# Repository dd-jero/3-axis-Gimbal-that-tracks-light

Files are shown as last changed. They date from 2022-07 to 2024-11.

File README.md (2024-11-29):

# Embedded System Capstone Design Project

## ✔️프로젝트 명
Gimbal system that tracks light
## ✔️ 개발 기간
2022.05 ~ 2022.06
## ✔️ 팀원 
|윤대민|[김태완](https://github.com/Waan2y) |[이재영](https://github.com/dd-jero)|
| :---: | :---: | :---: |
|팀장, I2C 통신 및 데이터 처리|PWM 설정 및 서보 모터 제어|Tracking 로직 구현|

## ✔️ 개발 환경 
- Chipset: ATmega4809(MCU), MCP2221A(USB-to-UART/I2C Convertor)
- Sensor: MPU6050, GL5549
- Servo motor
- Programming: AVR registers manipulation with C/C++
- 3D printing: Autodesk 3ds Max, UltiMaker Cura, Ender-3

## ✔️ 개발 목표
- 타깃 조준을 유지하는 미사일 발사대 컨셉

## ✔️ 주요 기능

### I2C 통신
- 센서 데이터 수집: MPU6050 센서로부터 가속도 및 자이로 데이터 수집
- **Drift Calibration**
  1. 배열 초기화
  2. 자이로스코트 데이터 읽기
  3. 값 저장 및 차이 계산 
  4. 드리트프 오류 추정
  
### PWM 제어
- TCA 레지스터를 사용한 PWM 신호를 신호를 생성하고 서보 모터 제어

### ADC 데이터 처리 
- CDS 센서의 아날로그 입력을 읽고 평균값을 계산하여 센서 오프셋 보정
- **Offset 설정**
  1. 초기화 및 데이터 수집
  2. 오프셋 계산
- **Offset 보정**
  1. 오프셋 적용
  2. 평균 값 계산
  3. 이동 상태 결정

### Tracking 및 자세 제어
1. ADC 데이터 처리
    - 수직 및 수평 이동 상태 결정 위해 상하좌우 평균값을 비교
2. 움직임 상태 결정
    - 수직 및 수평 상태 플래그를 설정하여 움직임 방향 결정
    - 특정 임계값 기준 
3. 최종 위치 조정 
    - tracking 각도 기반의 수평 및 수직 상태에 따른 조정
    - 최종적으로 각도 변환 후 PWM 신호를 통해 서보 모터 제어 

## ✔️ 회로도
<p align="center"> circuit</p>

## ✔️ 시스템 구현 모델
<p align="center"> model</p>

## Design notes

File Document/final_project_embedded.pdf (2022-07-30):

### 임베디드시스템 설계/2021

# 사물 tracking 3축 짐벌

# 최종 보고서

2022. 6. 19

# 인하대학교 정보통신공학부 윤대민, 김태완, 이재영

### 임베디드 시스템 설계/2022

정보통신공학부
임베디드시스템 설계

# 연구목표

## - 제목: 사물 tracking 3축 짐벌

## - 주요내용

- 사용자의 움직임으로 인한 카메라의 움직임을 보상하여, 카메라가 3차원의 특정

지점에서 움직이지 않도록 보조하는 장치를 구현한다.

- 카메라가 물체를 tracking하는 경우, 위 기능을 위한 데이터에, tracking으로 인한

카메라의 움직임을 반영하여, tracking과 짐벌이 동시에 동작할 수 있는 알고리즘을

구현하고 검증한다.

# 짐벌 시스템 예시

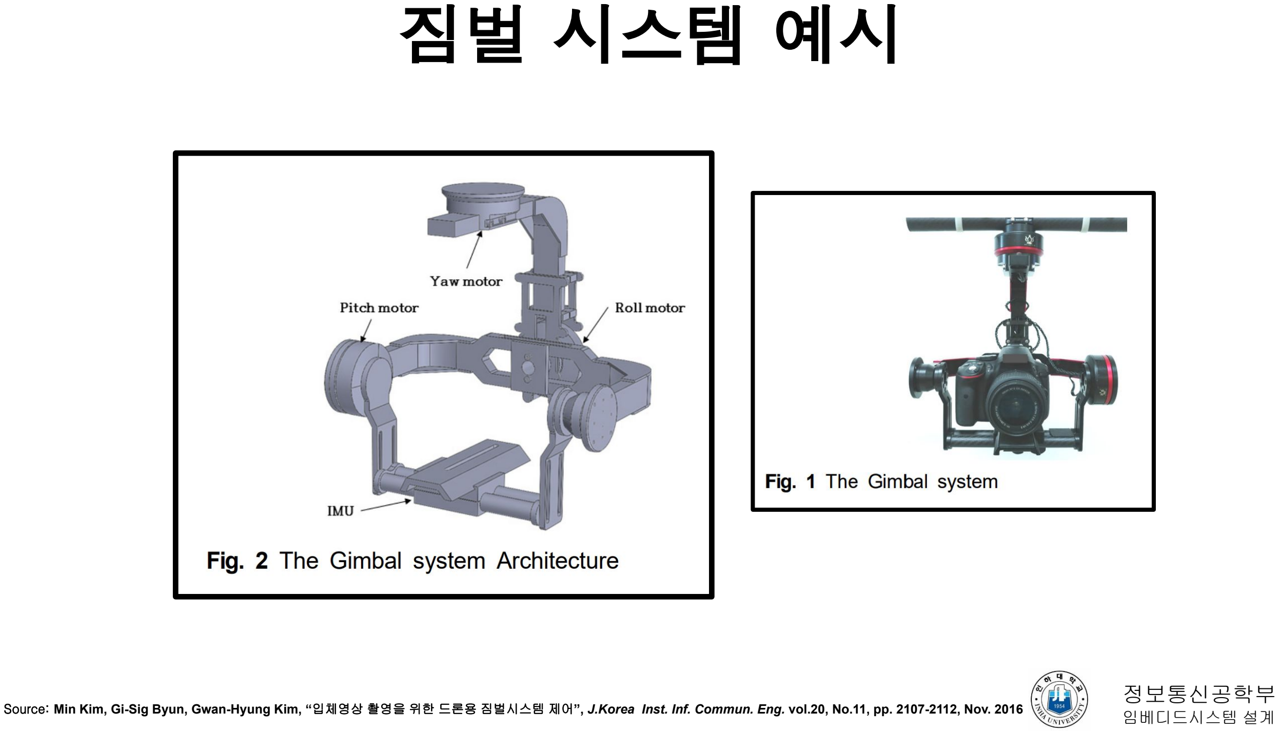
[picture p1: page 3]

Source: | Min Kim, Gi-Sig Byun, Gwan-Hyung Kim, “입체영상 촬영을 위한 드론용 짐벌시스템 제어”, J.Korea Inst. Inf. Commun. Eng. | vol.20, No.11, pp. 2107-2112, Nov. 2016

# 시스템 적용 예시

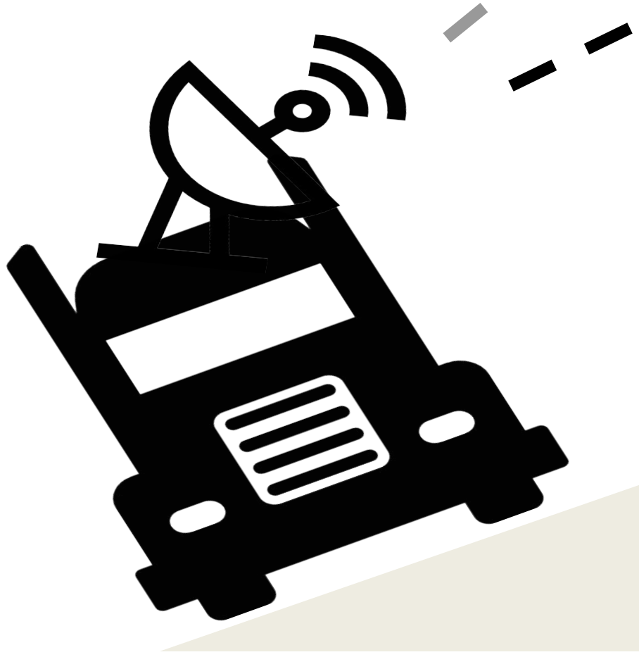
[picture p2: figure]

특정 타겟을 조준하고 있는 장비가 이동 중인 경우에도 조준을 유지할 수 있도록 한다.

# 시스템 구성 : Block Diagram

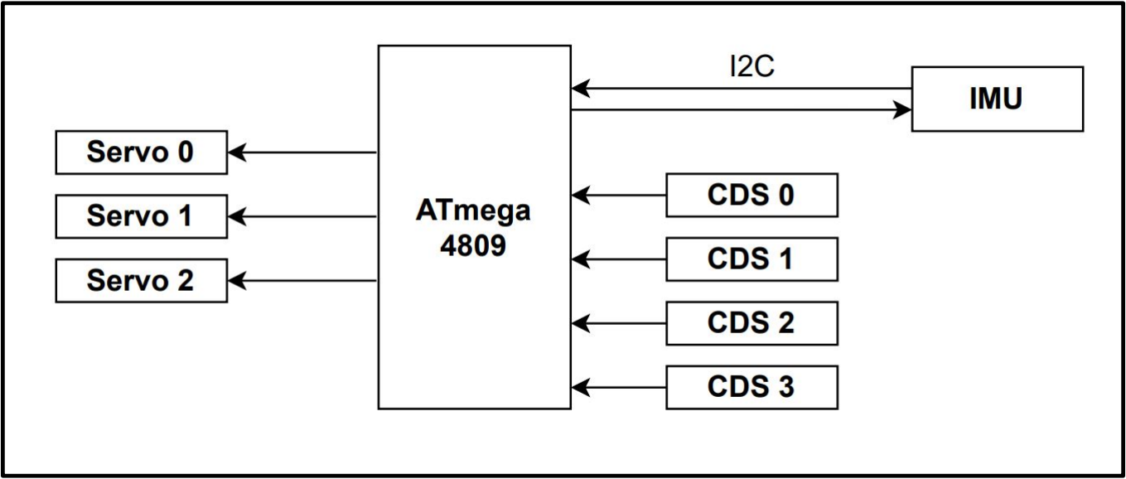
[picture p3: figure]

# 시스템 구성 : Flow-Chart

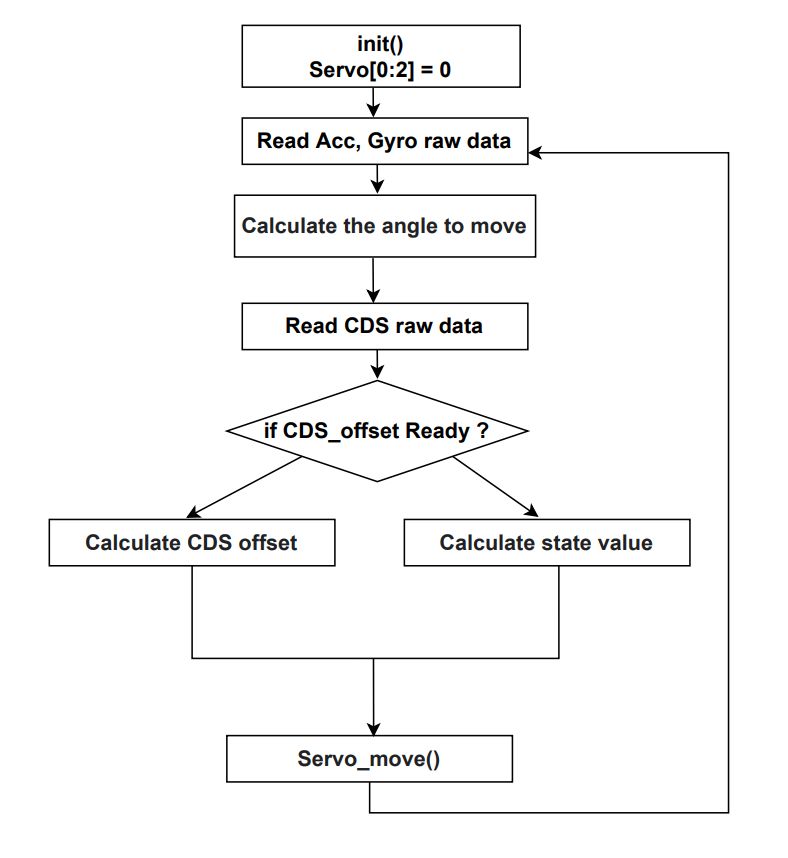
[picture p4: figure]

# 시스템 구성 : 회로도

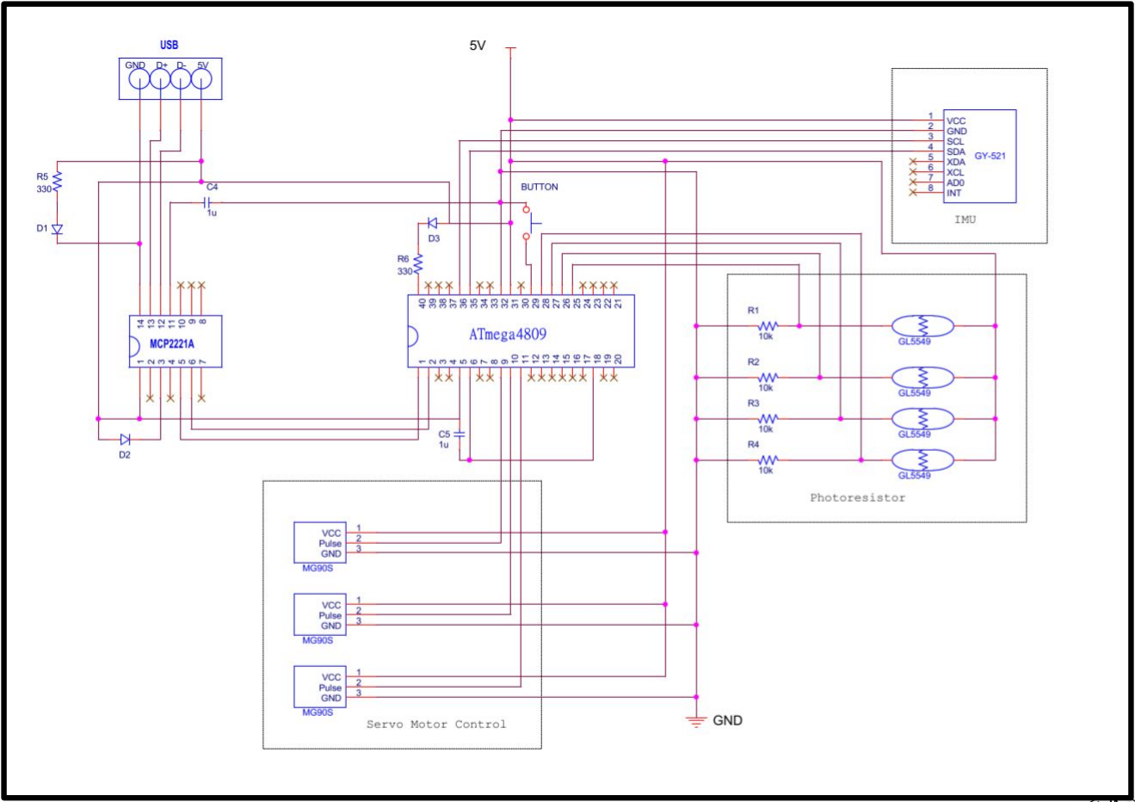
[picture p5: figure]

# 주요 부분 : 몸체

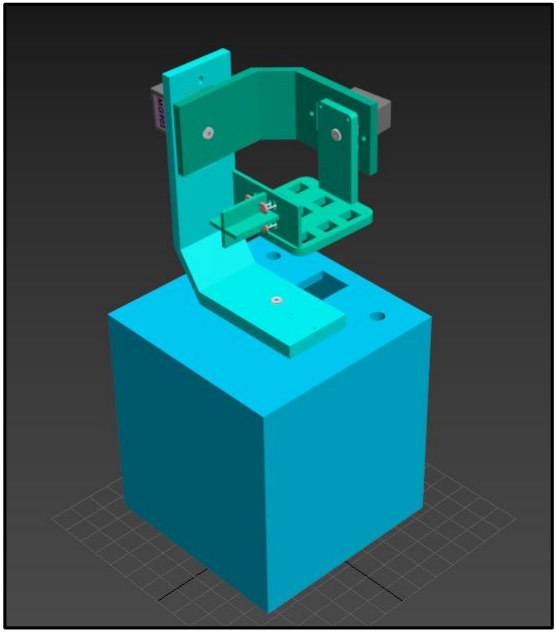
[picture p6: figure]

- 센서 측정값 수신
- IMU: 가속도, 각속도 측정값을 수신.

인터페이스: I2C

- 조도센서: 상하좌우 4방향에 해당하는 조도를 측정
- 데이터 취합 및 계산
- IMU의 측정값으로 Roll, Pitch, Yaw 정도를 계산
- CDS의 상/하, 좌/우 중 조도가 높은 방향(tracking 방향)

결정

- 기울기 보상을 위한 데이터와, tracking 을 위한 데이터를

계산하여 Servo의 이동 각도 산출

- 서보모터 제어
- 8-bit PWM

# 주요 기능 구현 : PWM

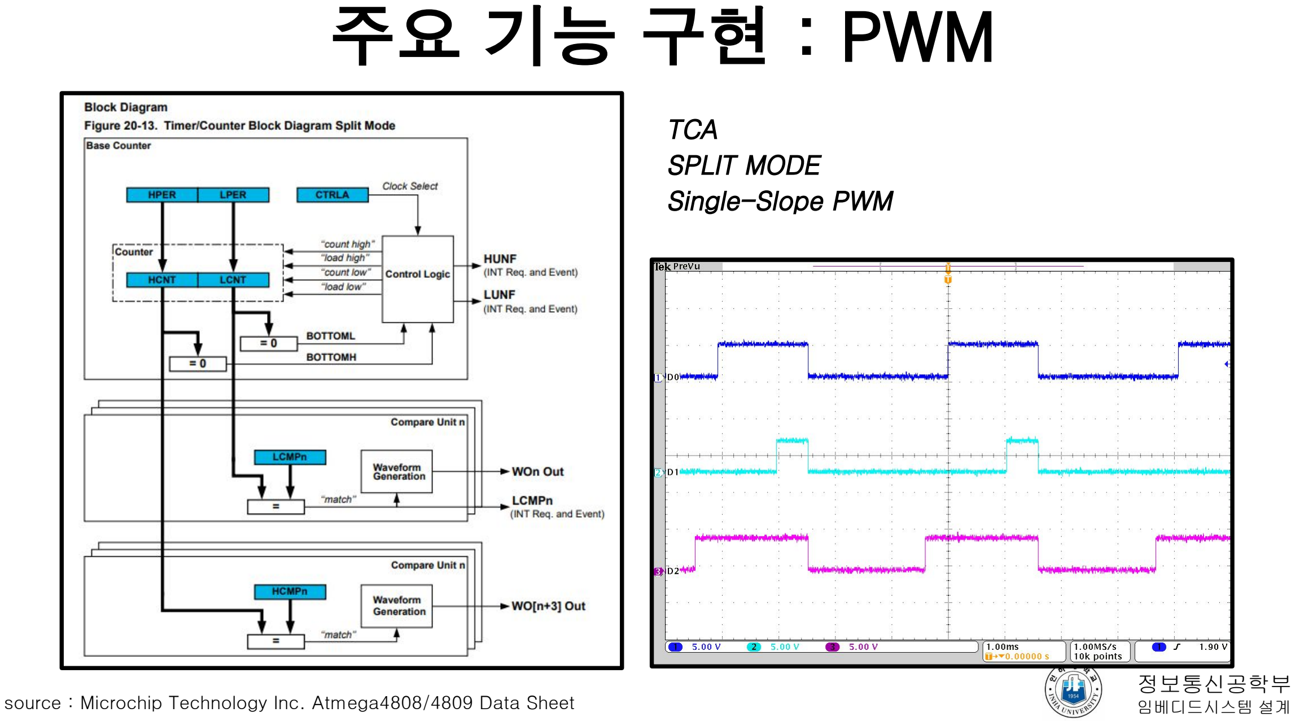
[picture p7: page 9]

TCA
SPLIT MODE
Single-Slope PWM

source : Microchip Technology Inc. Atmega4808/4809 Data Sheet

# 주요 기능 구현 : PWM

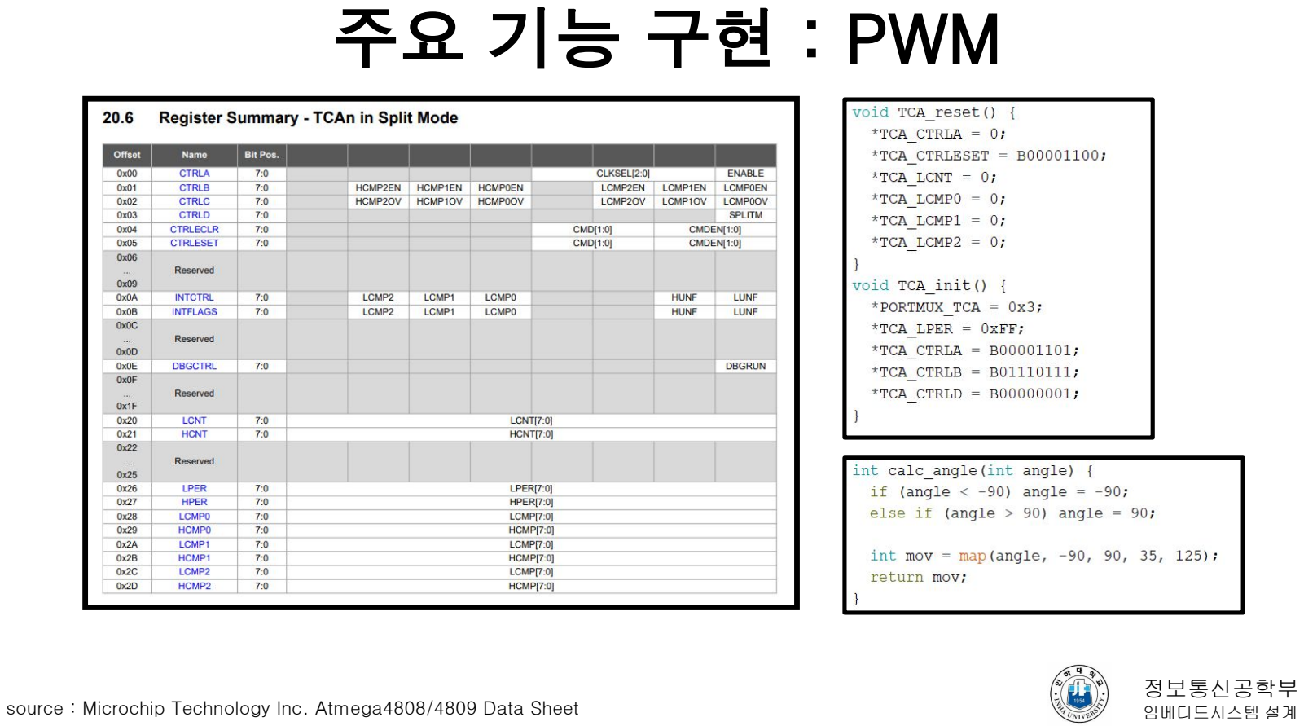
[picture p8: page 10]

source : Microchip Technology Inc. Atmega4808/4809 Data Sheet

# 주요 기능 : Tracking

- 조도 센서를 이용해서 광원의 위치를 파악한다.

### -상하좌우 4개의 조도센서를 사용하며, 각 조도센서로부터의 input이

동일해지도록 모듈을 제어한다.

- 광원 방향으로 이동하기 위해 서보모터에 전달해야 하는 값을 산출한다.

### - 자세 제어를 위해 계산한 데이터에 광원 트래킹을 위한 데이터를

더해줌으로써 두 종류의 기능이 동시에 동작하도록 한다.

# 주요 기능 구현 : ADC

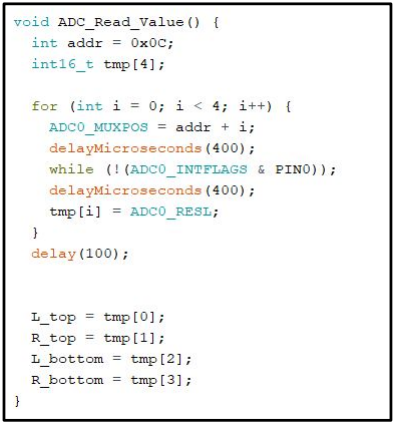
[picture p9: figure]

ADC의 MUXPOS Register를 이용하여 ADC 4개 채널 활용

- Atemga4809의 AIN12 ~ AIN15를 사용
=> 4개 CDS (GL5537)의 raw data 확인
- MUXPOS로 채널이 바뀌면서 settling time 필요 => 400us의 delay 부여
- 8bit resolution으로 0 ~ 255 값 출력
- ADC의 최대 분해능을 위해 CLK_PER를 16분주 (16MHz / 16 = 1MHz의 ADC Clock)

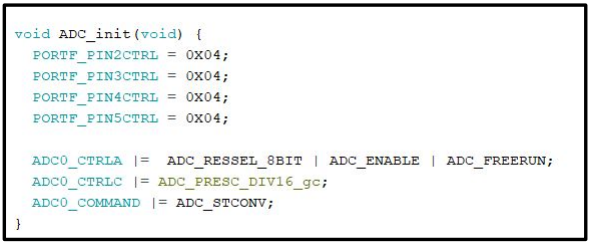
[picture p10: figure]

- Free Run Mode를 이용
=> conversion이 끝나자마자 새로운 conversion 시작

# 주요 기능 구현 : ADC

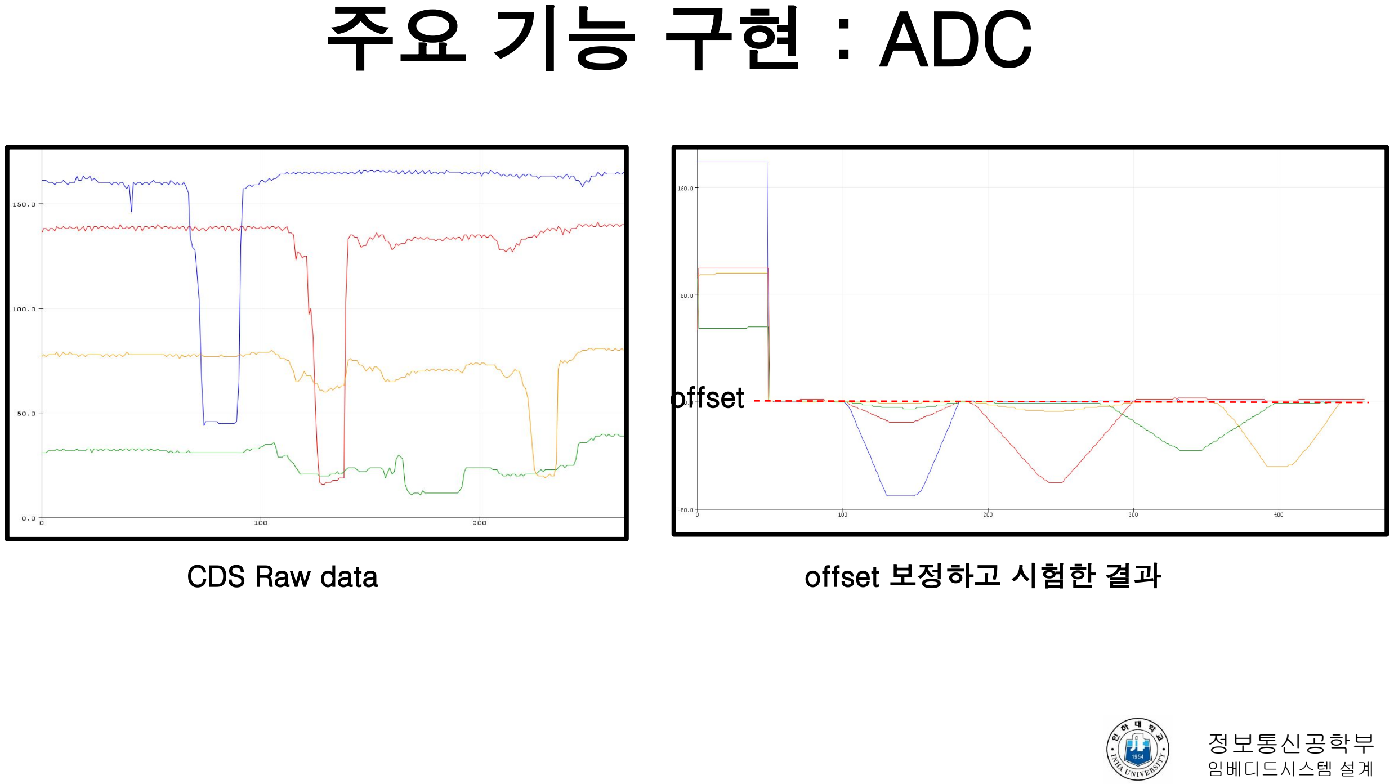
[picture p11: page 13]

CDS Raw data | offset 보정하고 시험한 결과

offset

# 주요 기능 구현 : ADC

### 환경적 요인을 고려한 raw data 보정

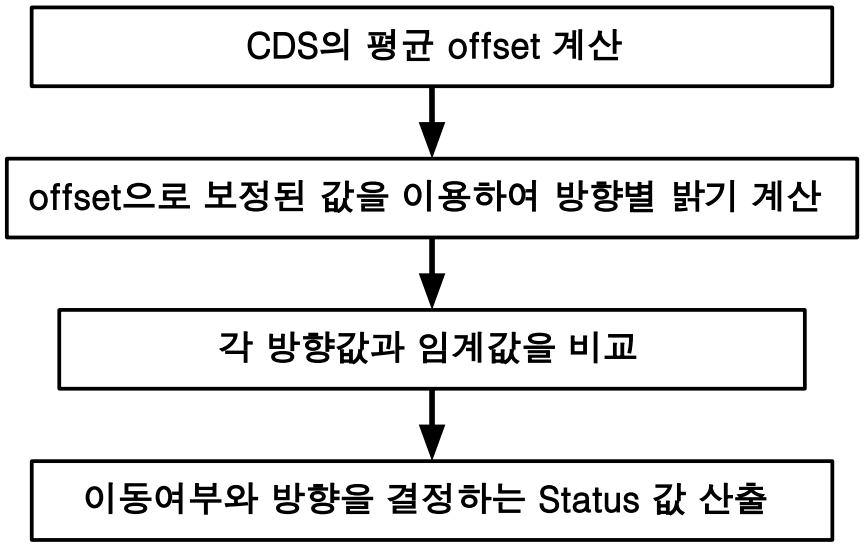
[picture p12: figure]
CDS의 평균 offset 계산; offset으로 보정된 값을 이용하여 방향별 밝기 계산; 각 방향값과 임계값을 비교; 이동여부와 방향을 결정하는 Status 값 산출

# 주요 기능 구현 : MPU6050

### 1. TWI_init

MCTRLA: twi_enable
MSTATUS: make bus idle

### 2. TWI_start

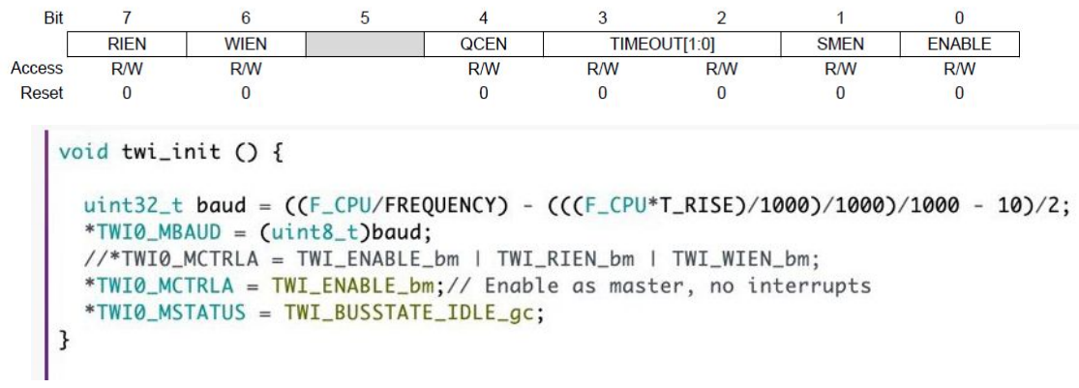
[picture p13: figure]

MADDR에 address <<1 | (RW’) 를 입력하면, MDATA를 거쳐 bus에 할당
polling 방식으로 WIF, RIF flag set을 기다림.
슬레이브로부터 ACK 수신을 감지하면 통신 종료

# 주요 기능 구현 : MPU6050

3. TWI_Write
start와 동일하게 전송하고자 하는 데이터를 mdata에 저장 MCTRLB에 통신 지속을 위해 TWI_MCMD_RECVTRANS 저장
4. TWI_Read
Read(0)은 데이터 read후 ACK를 전송. Read(1)은 데이터 read 후 NACK를 전송.
ACK 전송시 MCTRLB에 TWI_MCMD_RECVTRANS_gc 저장.
NACK 전송시 통신 종료를 위해 MCTRLB에 TWI_MCMD_STOP_gc 저장.

# 주요 기능 구현 : MPU6050

### 5. Sensor setting

*0x1A = 0x06 : 내장 LPF 사용

*0x1B = 0x08 : Scale range of gyro (±500°/s)

*0x1C = 0x00 : Scale range of accelerometer (±2g)

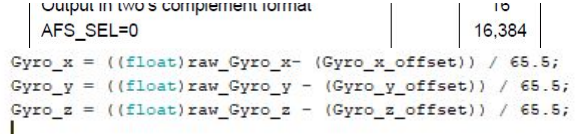
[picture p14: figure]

source : InvenSense Inc. MPU-6000/MPU-6050 Product Specification

# 주요 기능 구현 : MPU6050

### 6. 가속도 및 각속도 센서 값 수신

Burst read Sequence

해당 기능을 사용하여 0x3B로부터 Acx, Acy, Acz, temp, Gyx, Gyy, Gyz

총 14 바이트를 연속해서 Read할 수 있도록 작성

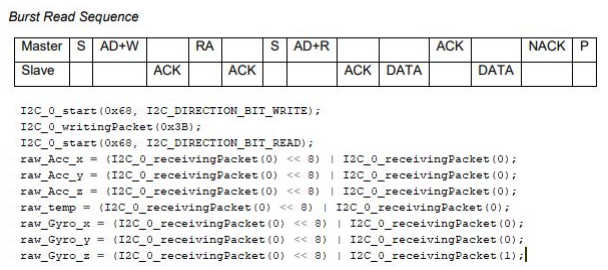
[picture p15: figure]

source : InvenSense Inc. MPU-6000/MPU-6050 Product Specification

# 주요 기능 구현 : MPU6050

### 7. Offset 계산

센서의 초기값에 오차가 있는 경우를 보정하기 위해 초기 100번의 평균값을 offset으로 설정

### 8. 각도 계산

가속도 센서: 중력 가속도 방향을 기준으로 Roll, Pitch 값을 얻을 수 있음

자이로 센서: 각 축을 기준으로 각속도를 적분하여 Roll, Pitch, Yaw값을 얻을 수 있음.

상보필터: 자이로센서와 가속도센서 계산 값을 상보필터에 적용하여, 정확성을 높일 수 있음.

장치의 움직임이 크지 않을 것이므로 각도 계산에는 가속도 센서값의 비중이 높은 상보필터를 사용

GyroCoef = 0.02

# 주요 기능 구현 : MPU6050

### 9. Drift Calibration

Yaw 값의 경우, 자이로센서 값만을 parameter로 사용. 따라서 누적되는 오차를 보정해 주는 알고리즘 추가

1. 정지 상태를 감지.

yaw 데이터 50개를 저장.

매 측정마다 데이터 변화량 49개를 저장. -> Diff 배열에 저장

Diff[0]과 Diff[48]의 평균과 전체 Diff의 평균의 특정 값 미만인 경우, 정지 상태로 판단.

2. Diff의 평균을 Drift로 간주
3. 계산한 drift값을 계산값에 적용하여 calibration 진행

# 주요 기능 구현 : MPU6050

### 9. Drift Calibration(상세 코드)

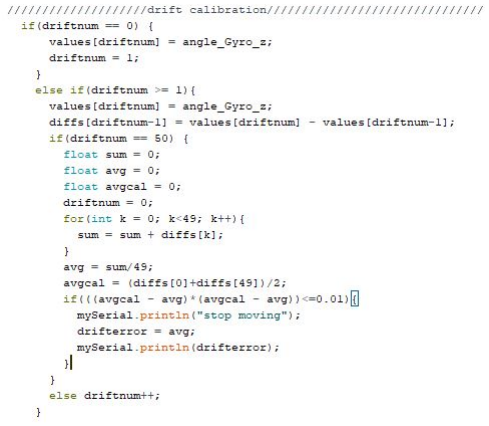
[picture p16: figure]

# 주요 기능 구현 : MPU6050

### Drift Calibration 검증

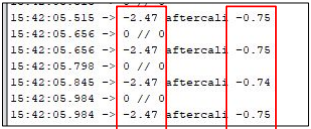
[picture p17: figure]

3분간 정지 상태 유지

calibration 이 적용되지 않은 경우 drift: -4°

calibration 알고리즘 적용한 경우 drift: -0.04°

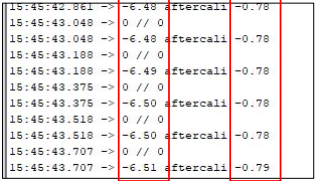
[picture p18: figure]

# 최종 기능 구현

### 1. 자세 제어 (짐벌) 앞서 계산된 각도 변화량만큼 반대로 서보모터를 구동함으로써 움직임을 보상해주도록 구현

# 최종 기능 구현

### 2. Tracking 4개의 input을 비교하여 Stay, move left, move right, move top, move bottom 5가지 state를 결정 하고, 계산된 각도에 Status를 반영하여 최종적으로 모터

제어.

# 최종 기능 구현

평균값의 차이가
threshold미만인 경우
target을 바라본다고 판단

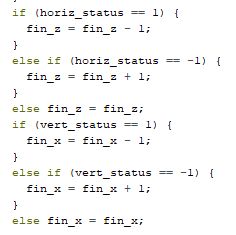
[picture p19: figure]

자세 변화 각도에, tracking을 위해 이동한 각도를 반영

=> 최종적으로 서보모터의 각도 결정
+
각도 유지를 위해 트래킹으로 인한 움직임을 저장

# 구현 중 문제점 및 고찰

### 1. 기기에 과도한 진동 발생

전기적 문제를 의심하였으나 전압, pwm signal이 모두 정상임을 확인. 특정 상태에서

무게중심이 문제가 되는 것을 확인하고 조정을 통해 보완

- 제품을 설계 할 때 전기적인 부분 외에도 다방면으로 고려해야 함을 인식

### 2. Tracking 알고리즘의 한계

자세 제어를 위해 움직였을 때, 축의 방향이 바뀌는 것을 고려하지 못함.

- 각도 범위를 지정하여 상태에 따라 축을 변경해주면 개선 가능할 것으로 예상

부품명 | 규격 (mm) | 모델/제조사 | 수량 | 가격(₩) | 비고
IMU | 21 x 11 x 1.5 | GY-521/ OEM | 1 | 3500/EA | I2C
조도센서 | 5.1 x 4.3 | GL5549/ OEM | 4 | 300/EA | -
서보모터 | 32.4 x 32.5 x 12 | MG90S/ OEM | 3 | 4200/EA | 무게 : 13.4g 토크 : 1.8kgf·cm
MCU | 50.8 x 15.24 x 5.06 | atmega4809/ MicroChip | 1 | - | -
배터리 | 60 x 34 x 50 | YJ Power Group YJ603450/ | 1 | 5500/EA | 3.7v 1000mAh 리튬폴리머배터리
만능기판 | 80 x 80 | - | 1 | 3000/EA | 양면

총 가격: 25800원

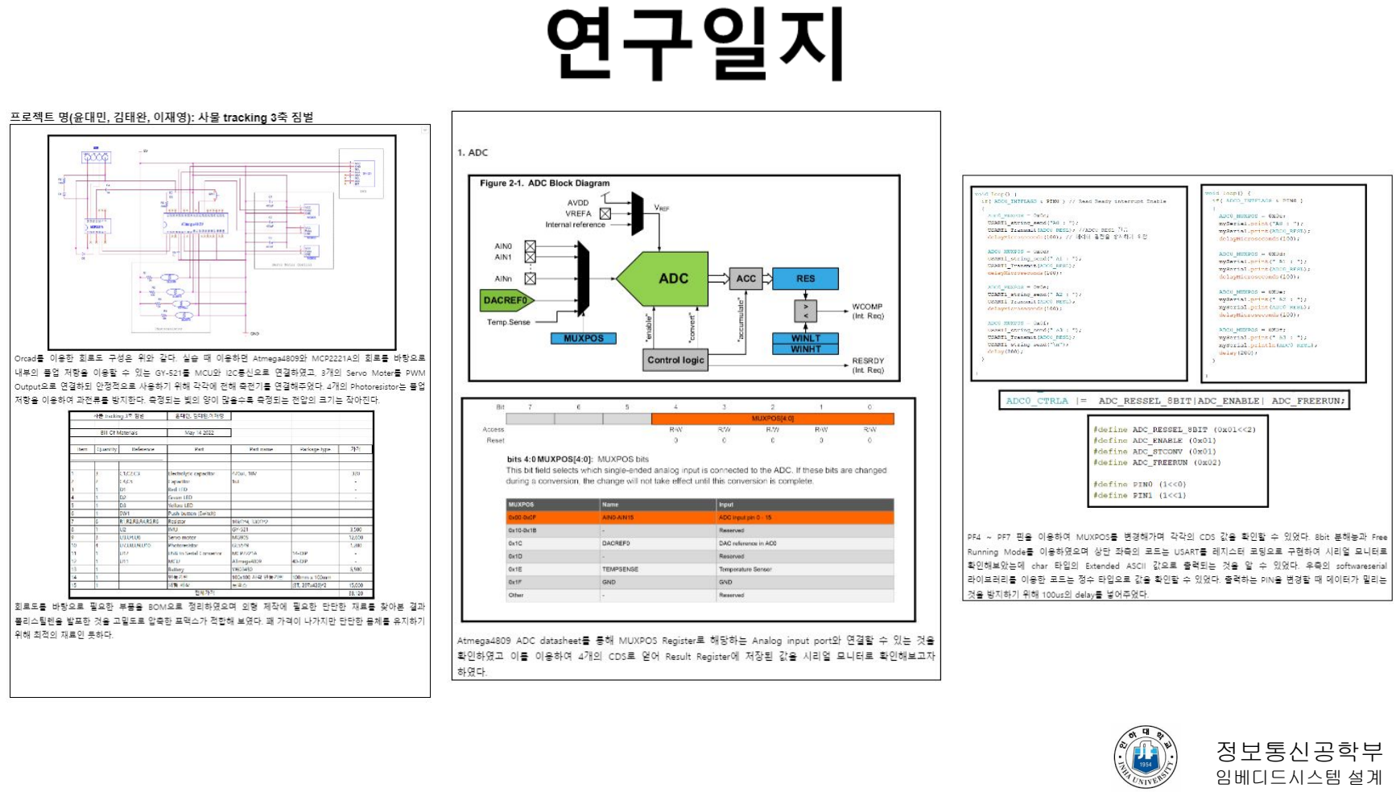
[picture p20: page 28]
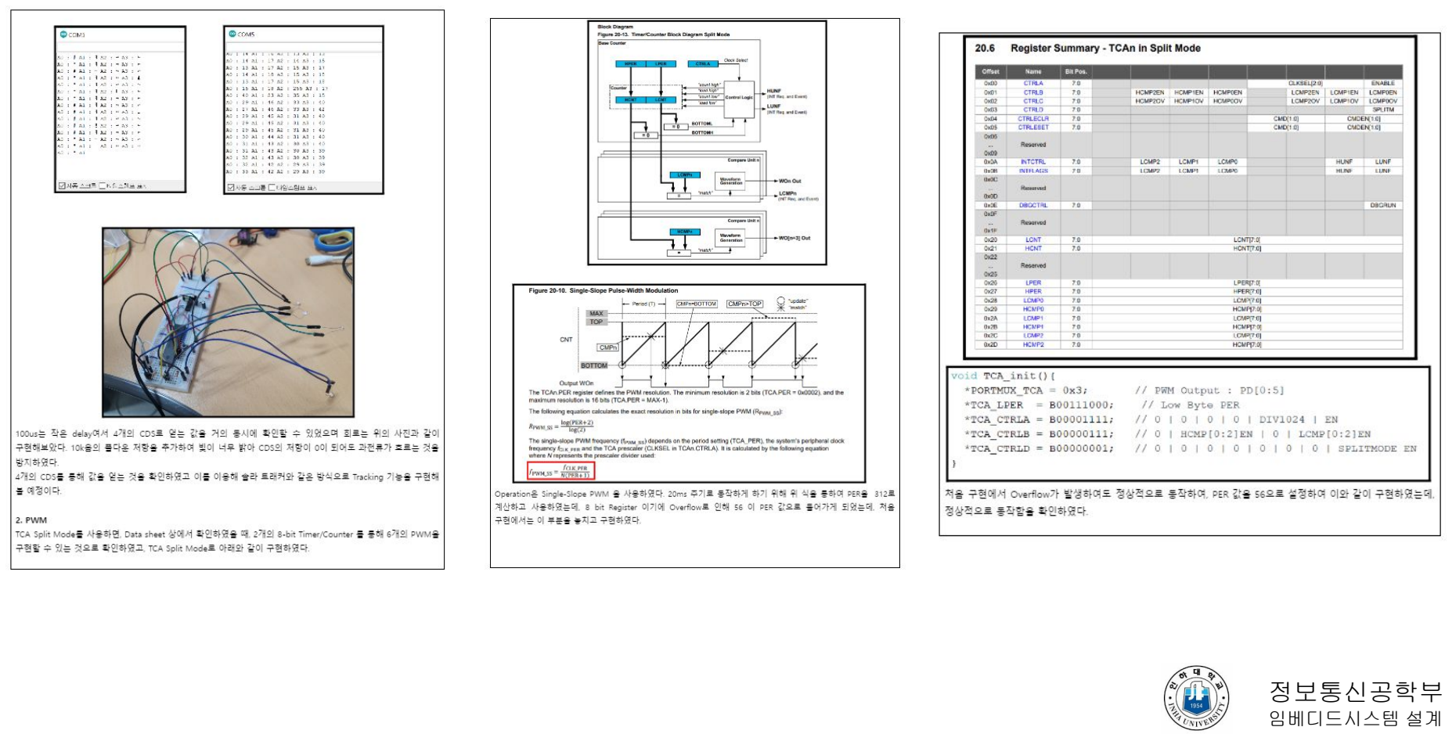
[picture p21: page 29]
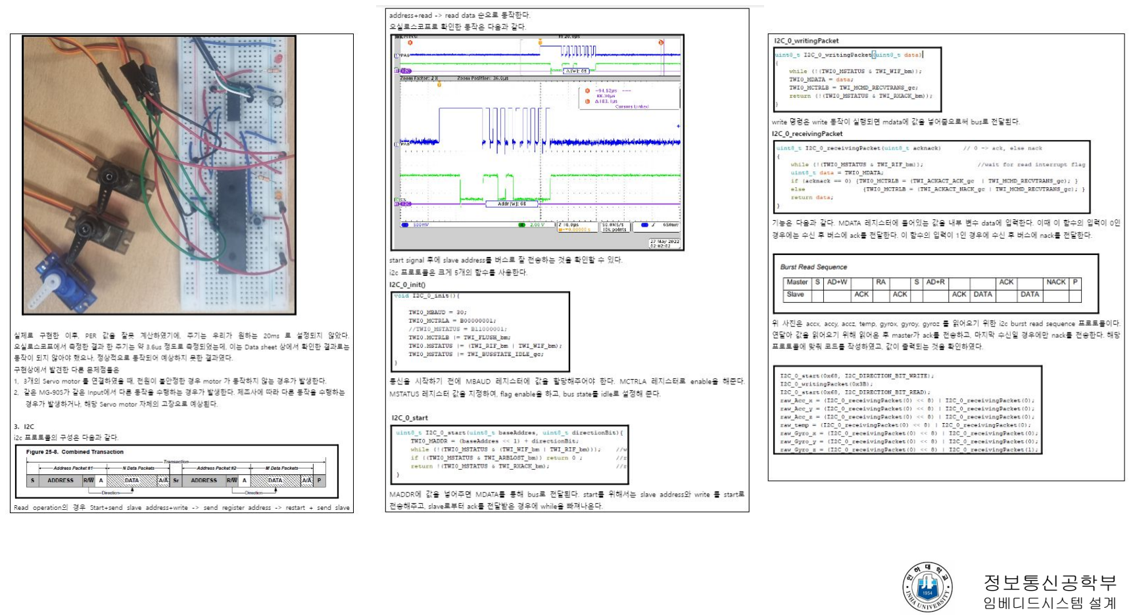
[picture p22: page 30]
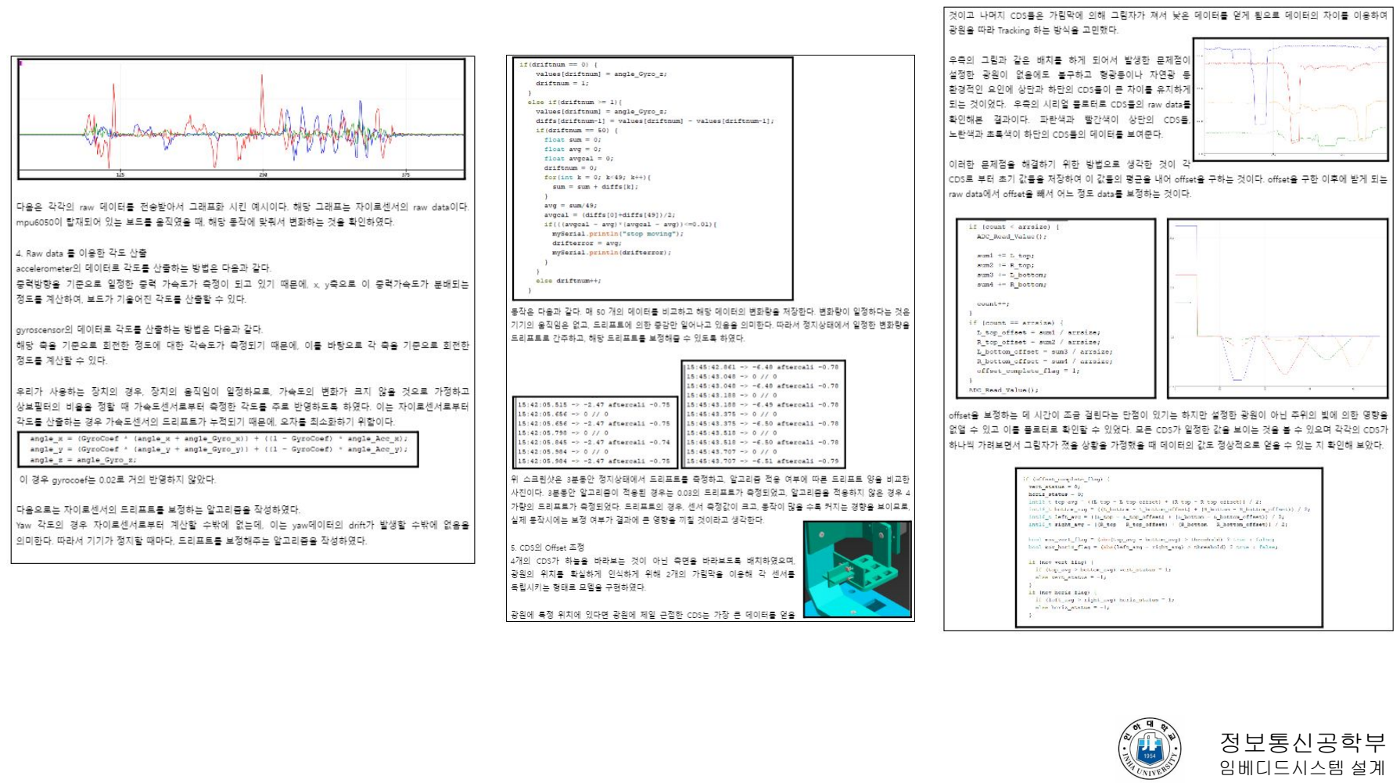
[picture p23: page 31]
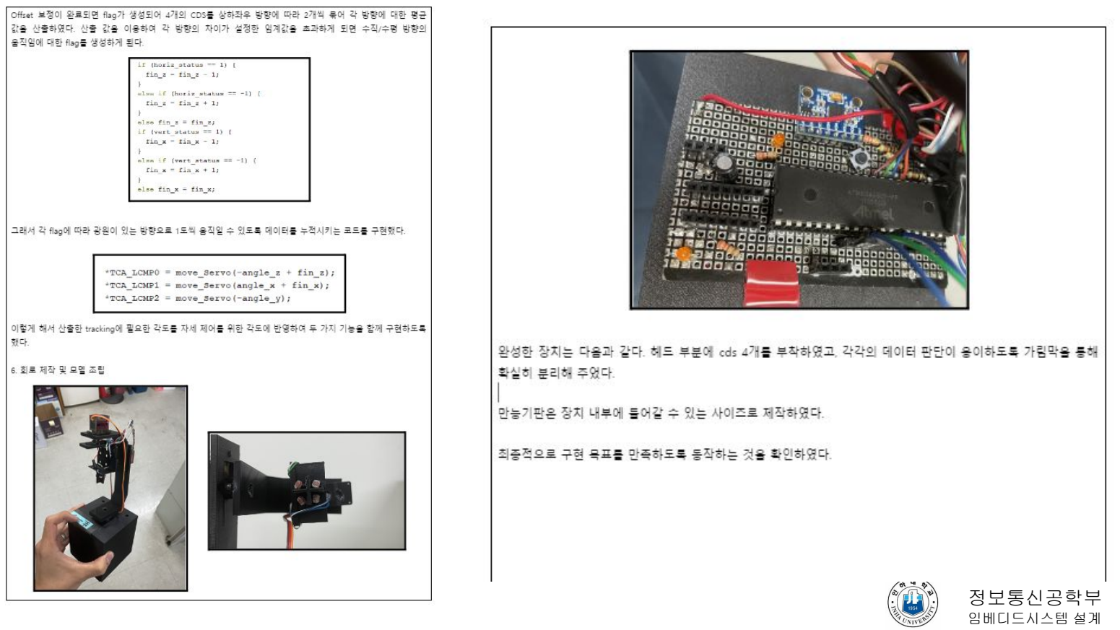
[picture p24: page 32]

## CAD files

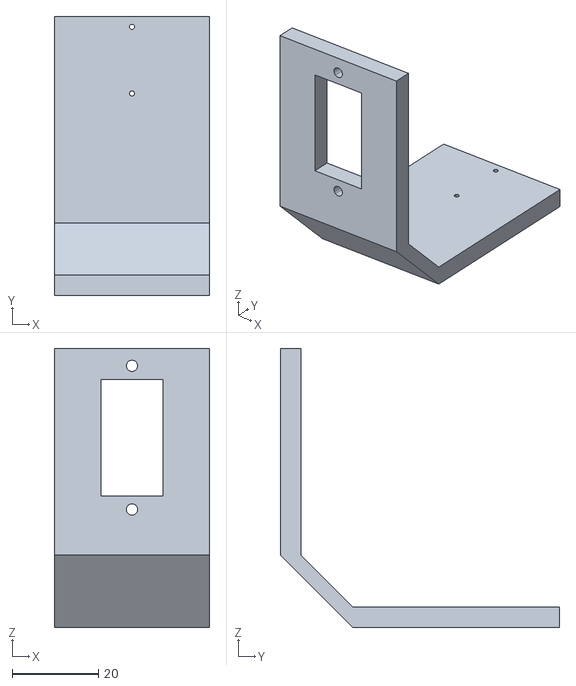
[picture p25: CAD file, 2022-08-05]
STL File/2sizeup.stl
36.0 x 64.8 x 64.8

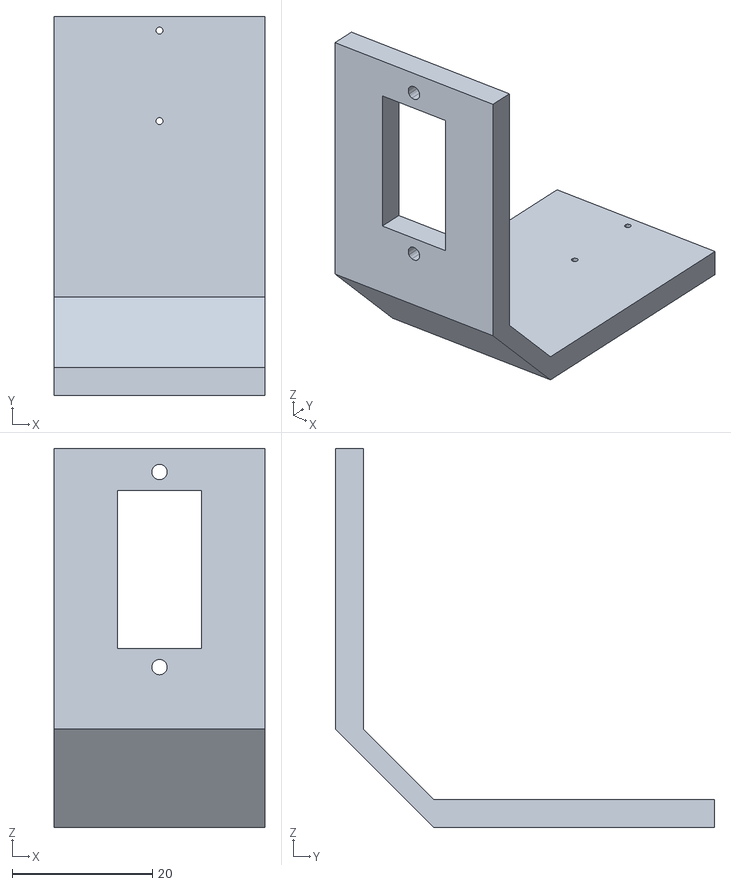
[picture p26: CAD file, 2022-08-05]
STL File/braket2.stl
30.0 x 54.0 x 54.0

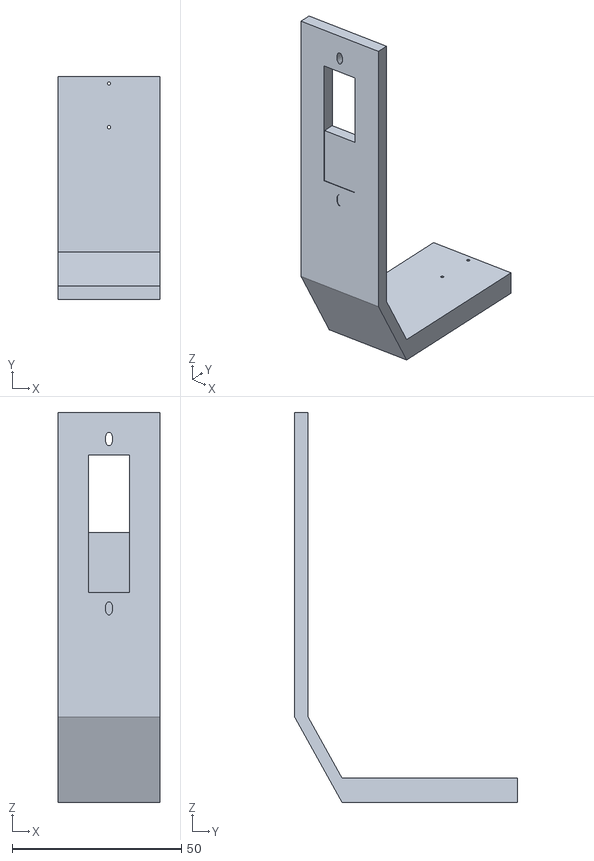
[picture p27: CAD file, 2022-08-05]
STL File/zaxis_115.stl
30.0 x 65.8 x 115.2

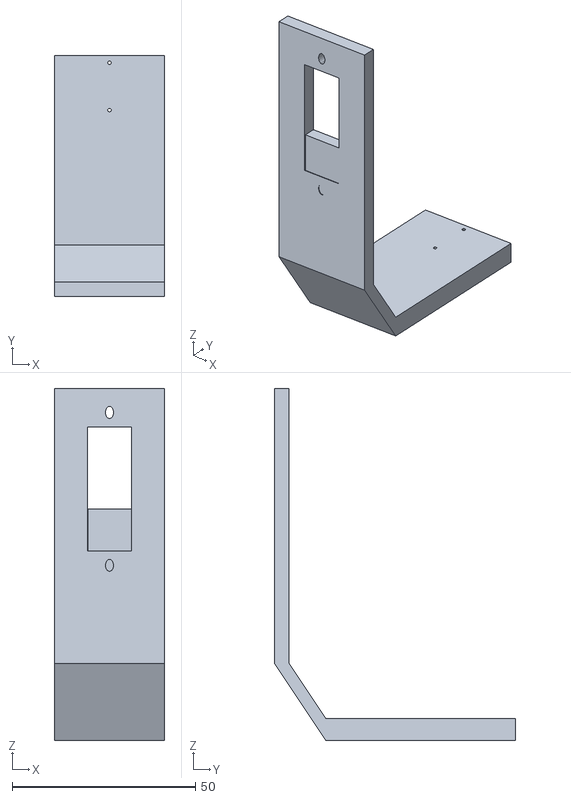
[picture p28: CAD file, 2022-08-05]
STL File/zaxis_10.stl
30.0 x 65.8 x 96.0

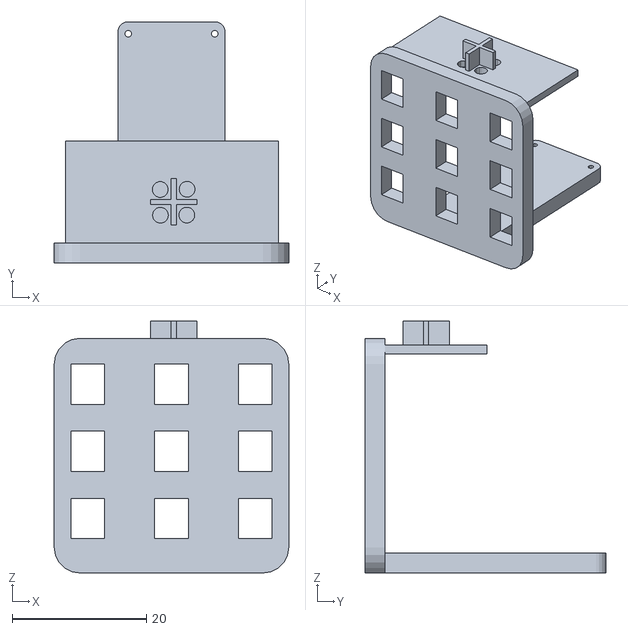
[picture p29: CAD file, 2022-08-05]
STL File/bracket_f.stl
35.0 x 36.0 x 37.6

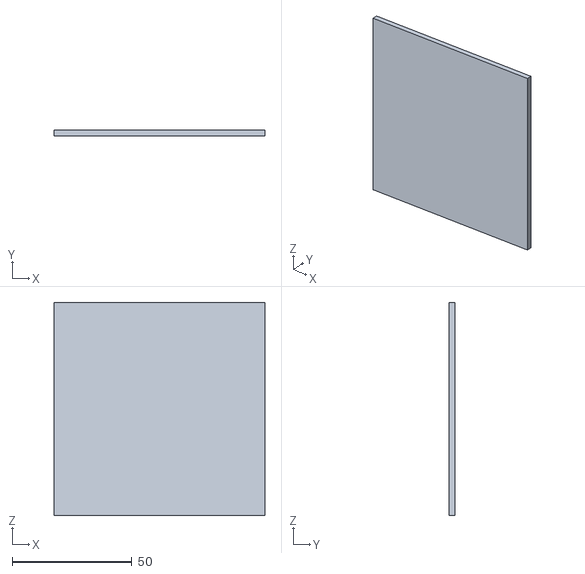
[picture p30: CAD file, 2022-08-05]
STL File/flat.stl
88.0 x 2.53 x 89.0

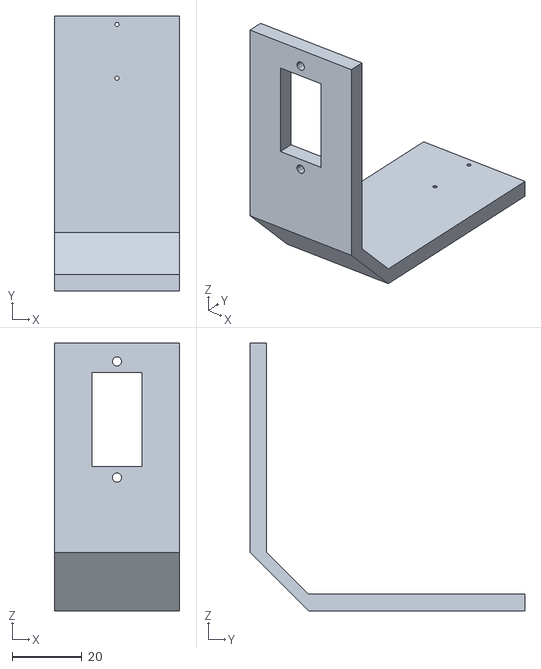
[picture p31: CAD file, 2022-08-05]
STL File/1sizeup.stl
36.0 x 78.9 x 76.8

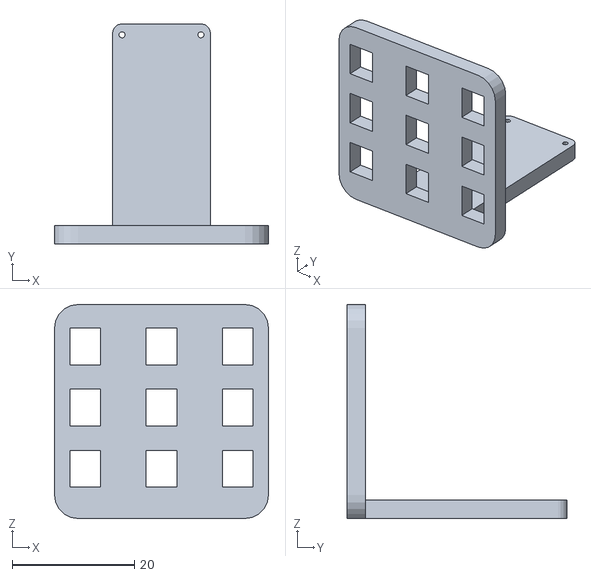
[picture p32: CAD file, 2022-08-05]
STL File/bracket.stl
35.0 x 36.0 x 35.0

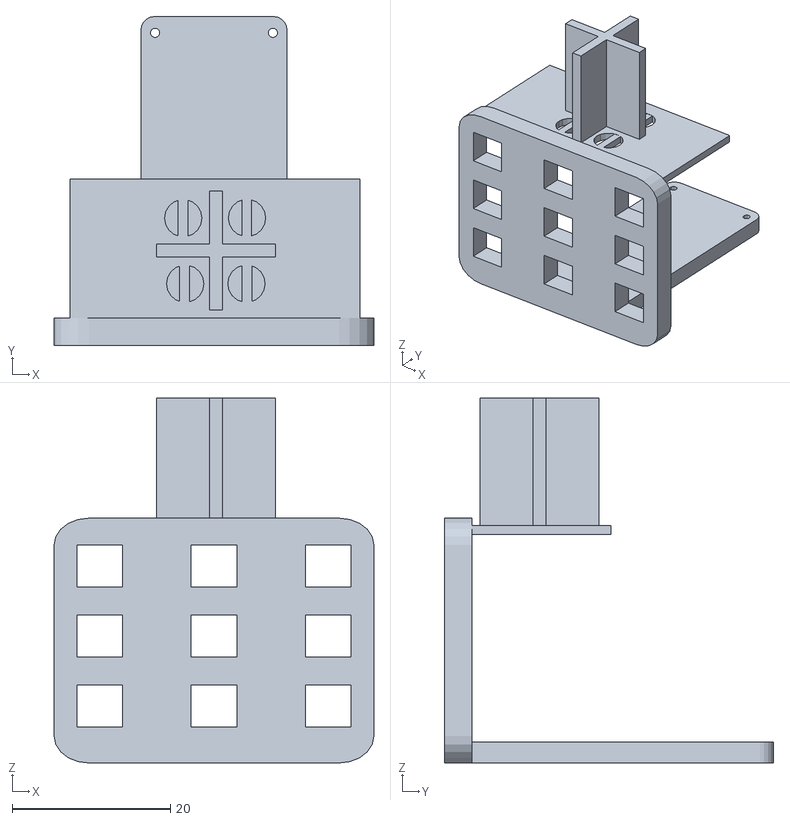
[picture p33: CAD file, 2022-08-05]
STL File/hole.stl
40.4 x 41.5 x 46.1

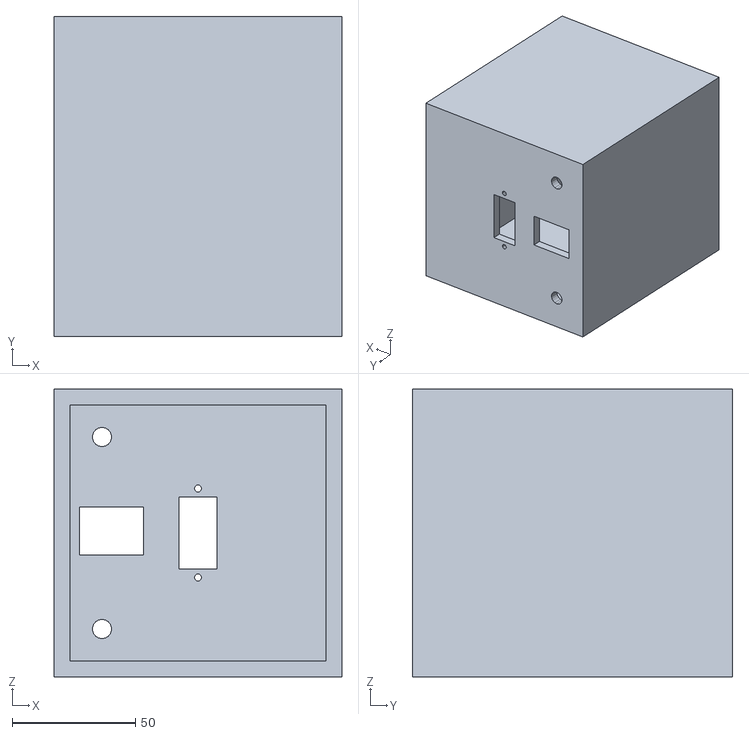
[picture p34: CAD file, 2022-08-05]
STL File/body_su.stl
117.0 x 130.0 x 117.0

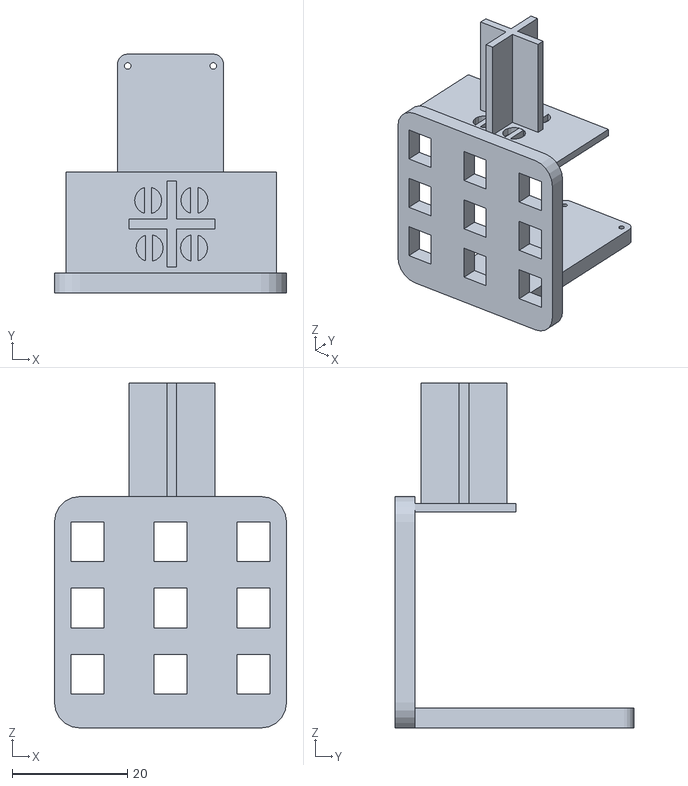
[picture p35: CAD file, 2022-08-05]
STL File/hole2.stl
40.4 x 41.5 x 60.0

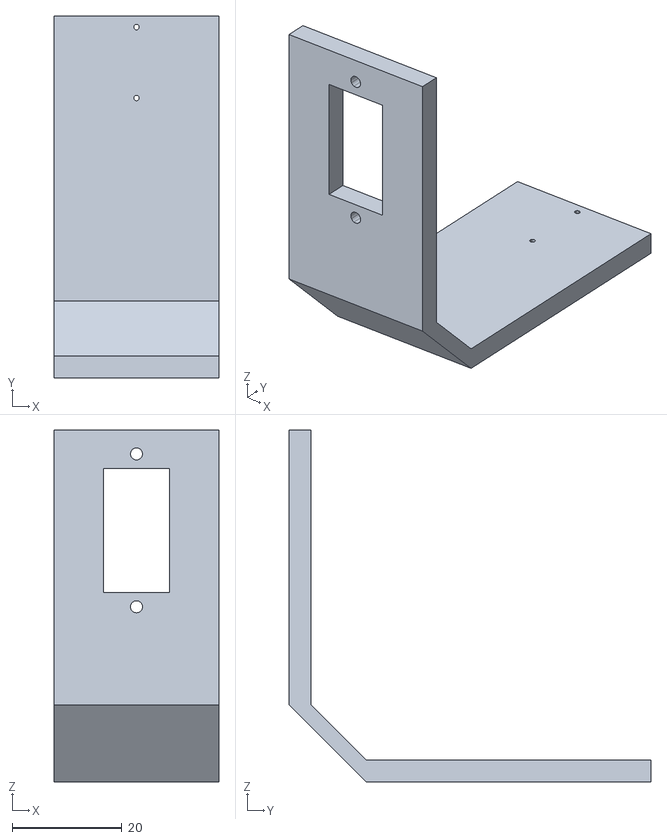
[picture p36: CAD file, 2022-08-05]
STL File/braket1.stl
30.0 x 65.8 x 64.0

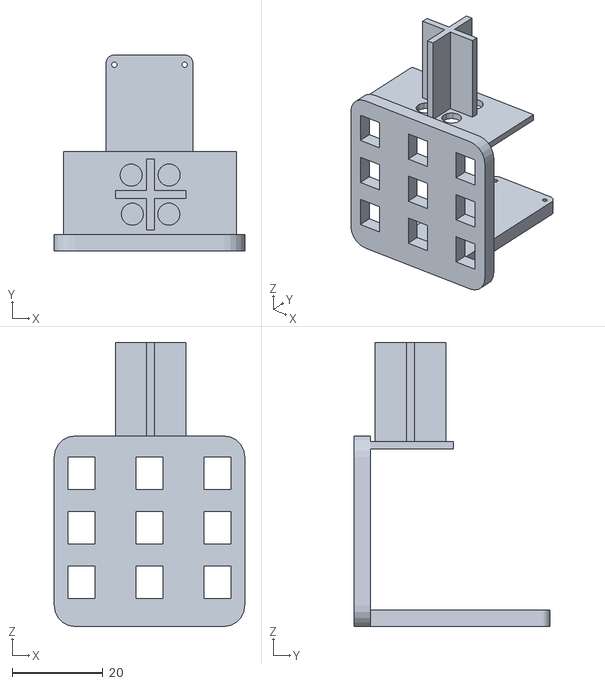
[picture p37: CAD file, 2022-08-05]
STL File/3sizeup.stl
42.0 x 43.2 x 62.6

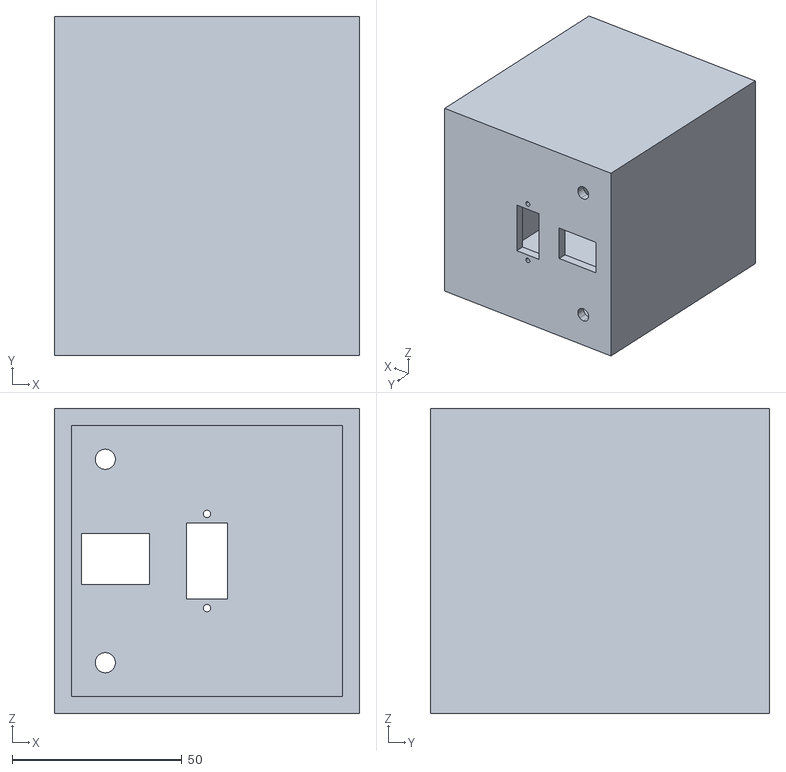
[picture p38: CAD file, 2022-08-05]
STL File/body.stl
90.0 x 100.0 x 90.0

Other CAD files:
STL File/zaxis.stl
STL File/flat_su.stl

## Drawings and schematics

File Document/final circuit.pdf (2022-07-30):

## IMU

5V

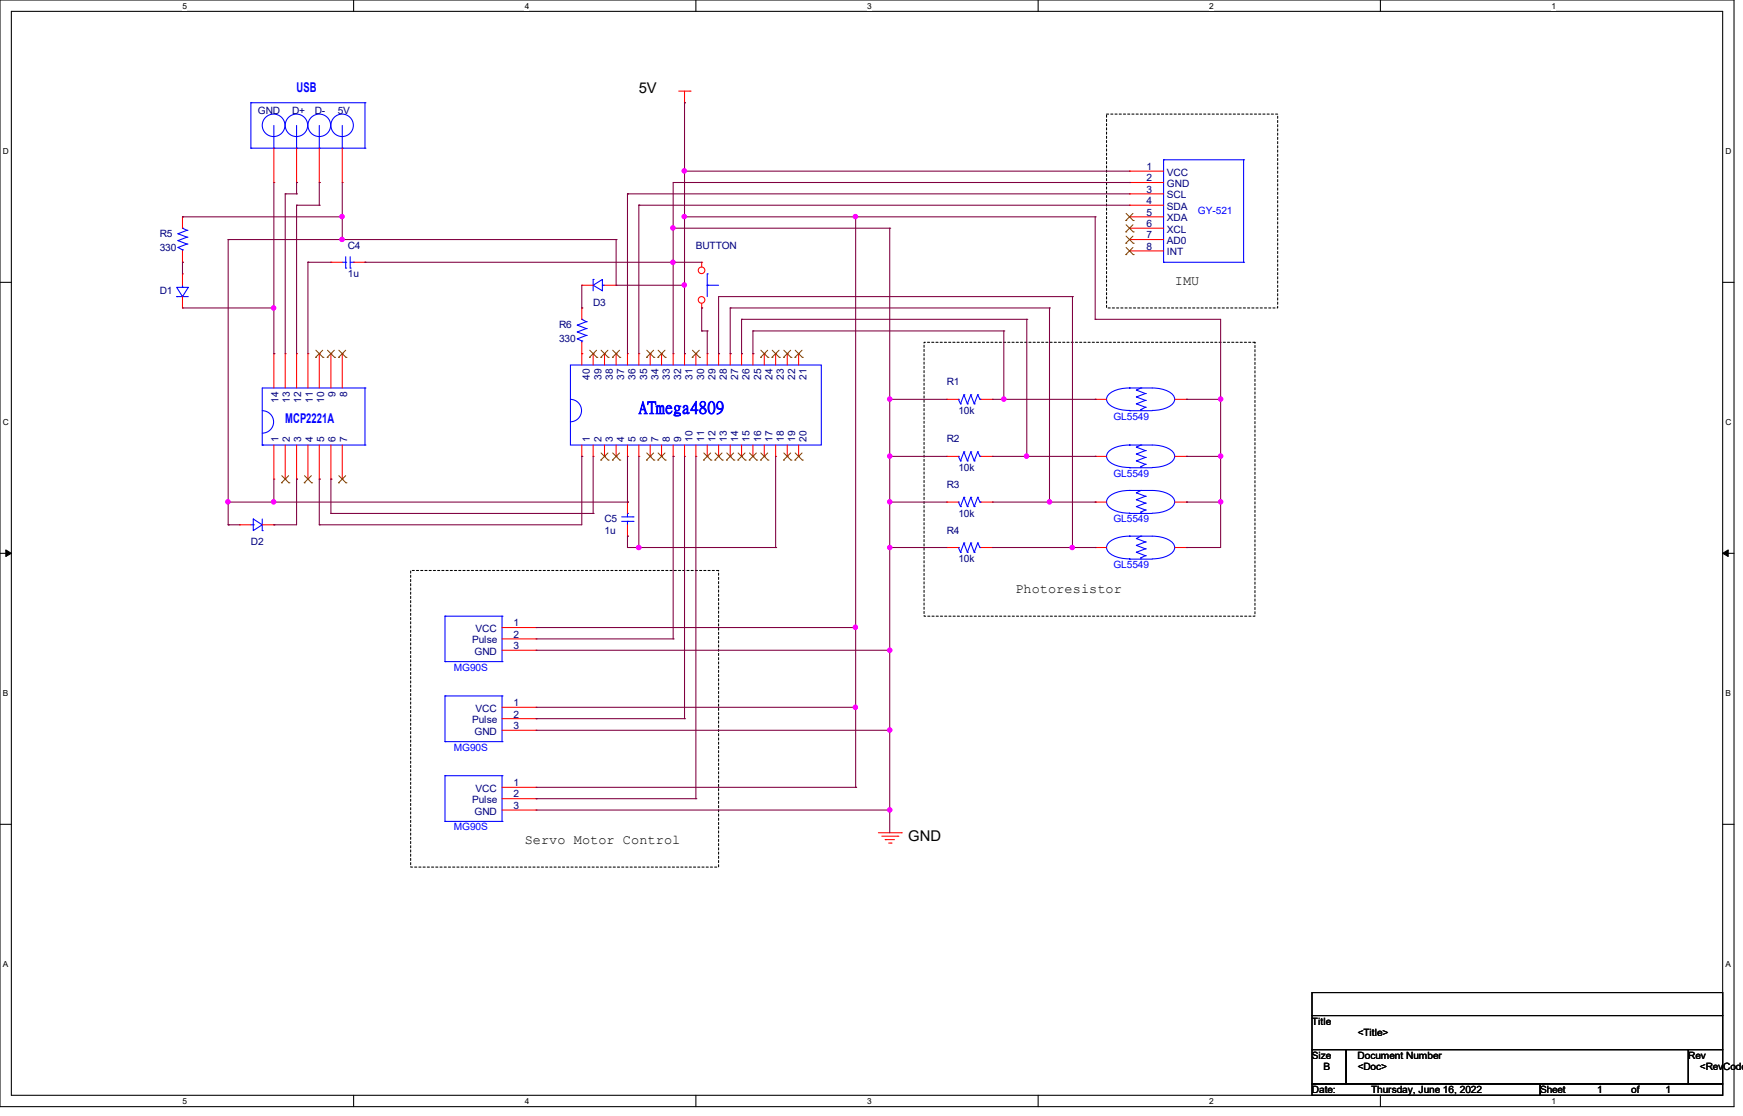
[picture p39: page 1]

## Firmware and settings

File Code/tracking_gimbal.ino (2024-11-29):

/*
    2022-1 임베디드시스템설계 최종프로젝트

    Team. 윤대민, 김태완, 이재영
    ver.  final_1
    date. 2022-06-15 14:49

    == Note ==
 *  * 정상 동작 시험 완료 *
    1. arrsize 커지면, 계산하는데 오래걸려서 빛을 지나쳐서 계속 가다 멈춰버림 -> arrsize 이제 사용 안해서 기능 없앰 함수 형태만 약간 수정
    2. x 축 다리길이 부족해서 걸림
    3. 이외 기능 모두 정상 동작
*/


// __ UART __ 구현상에서 사용하지는 않는 부분임. Data 확인 용
#include <SoftwareSerial.h>
SoftwareSerial mySerial(9, 8); // RX, TX

// __ I2C __

#define TWI0_BAUD(F_SCL)      ((((float)F_CPU / (float)F_SCL)) - 10 )
#define I2C_SCL_FREQ                                    400000
#define I2C_DIRECTION_BIT_WRITE                         0
#define I2C_DIRECTION_BIT_READ                          1
#define RAD_TO_DEG  (180 / 3.14159)

int16_t raw_Acc_x, raw_Acc_y, raw_Acc_z;
int16_t raw_temp;
int16_t raw_Gyro_x, raw_Gyro_y, raw_Gyro_z;
float Acc_x, Acc_y, Acc_z;
float Gyro_x, Gyro_y, Gyro_z;
float angle_Acc_x, angle_Acc_y, angle_Acc_z;
float angle_Gyro_x, angle_Gyro_y, angle_Gyro_z;
float angle_x = 0, angle_y = 0, angle_z = 0;
float Gyro_x_offset, Gyro_y_offset, Gyro_z_offset;
float Gyro_x_avg, Gyro_y_avg, Gyro_z_avg;
float fin_x, fin_y, fin_z;
float Interval;
float preInterval;
float cali_gyro;
float AccCoef = 0.98f;
float GyroCoef = 0.02f;


void I2C_0_init() {
  TWI0_MBAUD = 30;
  TWI0_MCTRLA = B00000001;
  //TWI0_MSTATUS = B11000001;
  TWI0.MCTRLB |= TWI_FLUSH_bm;
  TWI0.MSTATUS |= (TWI_RIF_bm | TWI_WIF_bm);
  TWI0_MSTATUS |= TWI_BUSSTATE_IDLE_gc;
}

void I2C_setup() {
  I2C_0_init();

  I2C_0_start(0x68, I2C_DIRECTION_BIT_WRITE);
  I2C_0_writingPacket(0x6B);
  I2C_0_writingPacket(0);
  I2C_0_stop();

  I2C_0_start(0x68, I2C_DIRECTION_BIT_WRITE);
  I2C_0_writingPacket(0x1A);
  I2C_0_writingPacket(0x06);
  I2C_0_stop();

  I2C_0_start(0x68, I2C_DIRECTION_BIT_WRITE);
  I2C_0_writingPacket(0x1B);
  I2C_0_writingPacket(0x08);
  I2C_0_stop();


  I2C_0_start(0x68, I2C_DIRECTION_BIT_WRITE);
  I2C_0_writingPacket(0x1C);
  I2C_0_writingPacket(0x00);
  I2C_0_stop();
}

uint8_t I2C_0_start(uint8_t baseAddres, uint8_t directionBit) {
  TWI0_MADDR = (baseAddres << 1) + directionBit;
  while (!(TWI0_MSTATUS & (TWI_WIF_bm | TWI_RIF_bm)));    //wait for write or read interrupt flag
  if ((TWI0_MSTATUS & TWI_ARBLOST_bm)) return 0 ;         //return 0 if bus error or arbitration lost
  return !(TWI0_MSTATUS & TWI_RXACK_bm);                  //return 1 if slave gave an ack
}

uint8_t I2C_0_writingPacket(uint8_t data) {
  while (!(TWI0_MSTATUS & TWI_WIF_bm));               //wait for write interrupt flag
  TWI0_MDATA = data;
  TWI0_MCTRLB = TWI_MCMD_RECVTRANS_gc;
  return (!(TWI0_MSTATUS & TWI_RXACK_bm));        //returns 1 if slave gave an ack
}

uint8_t I2C_0_receivingPacket(uint8_t acknack) {
  while (!(TWI0_MSTATUS & TWI_RIF_bm));               //wait for read interrupt flag
  uint8_t data = TWI0_MDATA;
  if (acknack == 0) {
    TWI0_MCTRLB = (TWI_ACKACT_ACK_gc  | TWI_MCMD_RECVTRANS_gc);
  }
  else                {
    TWI0_MCTRLB = (TWI_ACKACT_NACK_gc | TWI_MCMD_STOP_gc);
  }
  return data;
}

void I2C_0_stop(void) {
  TWI0_MCTRLB = (TWI_MCMD_STOP_gc);

}

void calcoffset() {
  int x = 0, y = 0, z = 0;
  uint16_t rx, ry, rz;
  for (int i = 0; i < 100; i++) {
    I2C_0_start(0x68, I2C_DIRECTION_BIT_WRITE);
    I2C_0_writingPacket(0x43);
    I2C_0_start(0x68, I2C_DIRECTION_BIT_READ);
    rx = (I2C_0_receivingPacket(0) << 8) | I2C_0_receivingPacket(0);
    ry = (I2C_0_receivingPacket(0) << 8) | I2C_0_receivingPacket(0);
    rz = (I2C_0_receivingPacket(0) << 8) | I2C_0_receivingPacket(1);

    x += ((float)rx);
    y += ((float)ry);
    z += ((float)rz);
  }

  Gyro_x_offset = x / 100;
  Gyro_y_offset = y / 100;
  Gyro_z_offset = z / 100;
}
// __ PWM __ ( via TCA )

#define PORTD_DIR   (unsigned char *)(0x0460)
#define PORTD_OUT   (unsigned char *)(0x0464)

#define PORTMUX_TCA (unsigned char *)(0x05E4)

#define TCA_CTRLA   (unsigned char *)(0x0A00)
#define TCA_CTRLB   (unsigned char *)(0x0A01)
#define TCA_CTRLD   (unsigned char *)(0x0A03)
#define TCA_CTRLESET     (unsigned char *)(0x0A05)
#define TCA_INTCTRL   (unsigned char *)(0x0A0A)
#define TCA_LCNT     (unsigned char *)(0x0A20)
#define TCA_HCNT     (unsigned char *)(0x0A21)
#define TCA_HPER     (unsigned char *)(0x0A26)
#define TCA_LPER     (unsigned char *)(0x0A27)
#define TCA_LCMP0    (unsigned char *)(0x0A28)
#define TCA_HCMP0    (unsigned char *)(0x0A29)
#define TCA_LCMP1    (unsigned char *)(0x0A2A)
#define TCA_HCMP1    (unsigned char *)(0x0A2B)
#define TCA_LCMP2    (unsigned char *)(0x0A2C)
#define TCA_HCMP2    (unsigned char *)(0x0A2D)

void TCA_reset() {
  *TCA_CTRLA = 0;
  *TCA_CTRLESET = B00001100;
  *TCA_HCNT = 0;
  *TCA_LCNT = 0;
  *TCA_HCMP0 = 0;
  *TCA_LCMP0 = 0;
  *TCA_HCMP1 = 0;
  *TCA_LCMP1 = 0;
  *TCA_HCMP2 = 0;
  *TCA_LCMP2 = 0;
}

void TCA_init() {
  *PORTMUX_TCA = 0x3;
  *TCA_LPER = 1250;
  *TCA_HPER = 1250;
  *TCA_CTRLA = B00001101;   // DIV1024
  *TCA_CTRLB = B01110111;
  *TCA_CTRLD = B00000001;   //SPLITMODE EN
  // *TCA_INTCTRL = B01110000;
  // TCA0.SINGLE.EVCTRL &= ~(TCA_SINGLE_CNTEI_bm);

}

void PORT_init() {
  *PORTD_DIR = B00011111;
  *PORTD_OUT = B00011111;
}

int move_Servo(int angle) {
  if (angle < -90) angle = -90;
  else if (angle > 90) angle = 90;

  int mov = map(angle, -90, 90, 32, 157);
  return mov;
}


// __ ADC __

#define ADC_RESSEL_10BIT (0x00<<2)
#define ADC_RESSEL_8BIT (0x01<<2)
#define ADC_ENABLE (0x01)
#define ADC_STCONV (0x01)
#define ADC_FREERUN (0x02)
#define PIN0 (1<<0)


int16_t tmp_L_top_offset = 0;
int16_t tmp_R_top_offset = 0;
int16_t tmp_L_bottom_offset = 0;
int16_t tmp_R_bottom_offset = 0;

int16_t L_top_offset = 0;
int16_t R_top_offset = 0;
int16_t L_bottom_offset = 0;
int16_t R_bottom_offset = 0;

int16_t L_top = 0;     // Left top
int16_t L_bottom = 0;  // Left bottom
int16_t R_top = 0;     // Right top
int16_t R_bottom = 0;  // Right bottom

int16_t avg_L_top = 0;     // prev Left top
int16_t avg_L_bottom = 0;  // prev Left bottom
int16_t avg_R_top = 0;     // prev Right top
int16_t avg_R_bottom = 0;  // prev Right bottom

int16_t avg_top;     // average top
int16_t avg_bottom;  // average bottom
int16_t avg_left;    // average left
int16_t avg_right;   // average right

int16_t threshold = 28;

void ADC_init(void) {
  PORTF_PIN2CTRL = 0X04; // PF0 interrupt and digital input buffer disabled
  PORTF_PIN3CTRL = 0X04; // PF1 interrupt and digital input buffer disabled
  PORTF_PIN4CTRL = 0X04; // PF2 interrupt and digital input buffer disabled
  PORTF_PIN5CTRL = 0X04; // PF3 interrupt and digital input buffer disabled

  ADC0_CTRLA |=  ADC_RESSEL_8BIT | ADC_ENABLE | ADC_FREERUN; // 8bit resolution and ADC enabled, FREERUN
  ADC0_CTRLC |= ADC_PRESC_DIV16_gc;
  ADC0_COMMAND |= ADC_STCONV; // Start conversion
}


void ADC_Read_Value() {
  int addr = 0x0C;
  int16_t tmp[4];

  for (int i = 0; i < 4; i++) {
    ADC0_MUXPOS = addr + i;             // A12~ (left top)
    delayMicroseconds(400);
    while (!(ADC0_INTFLAGS & PIN0));
    delayMicroseconds(400);
    tmp[i] = ADC0_RESL;
  }
  delay(100);                     // 가능하면 줄이고 싶음 ( ADC delay 싹다 )


  L_top = tmp[0];
  R_top = tmp[1];
  L_bottom = tmp[2];
  R_bottom = tmp[3];
}

void ADC_calc_AVG(int16_t L_top, int16_t R_top, int16_t L_bottom, int16_t R_bottom) {
  avg_top = (L_top + R_top) / 2;
  avg_bottom = (L_bottom + R_bottom) / 2;
  avg_left = (L_top + L_bottom) / 2;
  avg_right = (R_top + R_bottom) / 2;
}

// __ main_ setup __
void setup() {

  I2C_0_init();
  I2C_setup();
  calcoffset();

  mySerial.begin(115200);

  TCA_reset();
  TCA_init();
  PORT_init();
  *TCA_LCMP0 = move_Servo(0);
  *TCA_LCMP1 = move_Servo(0);
  *TCA_LCMP2 = move_Servo(0);

  ADC_init();
}

// __ main_ loop __
int count = 0;
int mov_vert = 0;
int mov_horiz = 0;
bool mov_vert_flag = false;
bool mov_horiz_flag = false;
int offset_flag = 1;
bool offset_complete_flag = false;

#define  arrsize 10
int16_t tmp1, tmp2, tmp3, tmp4;
int16_t sum1, sum2, sum3, sum4;
int horiz_status = 0;
int vert_status = 0;
//////////////////////////////////////////////////////////////////for drift calibration///////////////////////////////////////////////
int driftnum = 0;
float values[50] = {0};
float diffs[49] = {0};
float drifterror = 0;
float nocalibz = 0;

void loop() {
  //  _____ Read GY-521(MPU6050) via I2C _____

  I2C_0_start(0x68, I2C_DIRECTION_BIT_WRITE);
  I2C_0_writingPacket(0x3B);
  I2C_0_start(0x68, I2C_DIRECTION_BIT_READ);
  raw_Acc_x = (I2C_0_receivingPacket(0) << 8) | I2C_0_receivingPacket(0);
  raw_Acc_y = (I2C_0_receivingPacket(0) << 8) | I2C_0_receivingPacket(0);
  raw_Acc_z = (I2C_0_receivingPacket(0) << 8) | I2C_0_receivingPacket(0);
  raw_temp = (I2C_0_receivingPacket(0) << 8) | I2C_0_receivingPacket(0);
  raw_Gyro_x = (I2C_0_receivingPacket(0) << 8) | I2C_0_receivingPacket(0);
  raw_Gyro_y = (I2C_0_receivingPacket(0) << 8) | I2C_0_receivingPacket(0);
  raw_Gyro_z = (I2C_0_receivingPacket(0) << 8) | I2C_0_receivingPacket(1);

  // raw -> data
  Acc_x = ((float)raw_Acc_x) / 16384.0;
  Acc_y = ((float)raw_Acc_y) / 16384.0;
  Acc_z = ((float)raw_Acc_z) / 16384.0;

  angle_Acc_x = atan2(Acc_y, sqrt(Acc_z * Acc_z + Acc_x * Acc_x)) * 360 / 2.0 / PI;
  angle_Acc_y = atan2(Acc_x, sqrt(Acc_z * Acc_z + Acc_y * Acc_y)) * 360 / -2.0 / PI;

  Gyro_x = ((float)raw_Gyro_x - (Gyro_x_offset)) / 65.5;
  Gyro_y = ((float)raw_Gyro_y - (Gyro_y_offset)) / 65.5;
  Gyro_z = ((float)raw_Gyro_z - (Gyro_z_offset)) / 65.5;

  Interval = (millis() - preInterval) * 0.001;

  angle_Gyro_x += Gyro_x * Interval;
  angle_Gyro_y += Gyro_y * Interval;
  angle_Gyro_z += Gyro_z * Interval;
  //cali_gyro += Gyro_z * Interval;

  angle_x = (GyroCoef * (angle_x + angle_Gyro_x)) + ((1 - GyroCoef) * angle_Acc_x);
  angle_y = (GyroCoef * (angle_y + angle_Gyro_y)) + ((1 - GyroCoef) * angle_Acc_y);
  angle_z = angle_Gyro_z;
  angle_Gyro_z -= drifterror;
  mySerial.print(angle_z);
  mySerial.print(" aftercali ");
  mySerial.println(cali_gyro);
  preInterval = millis();
////////////////////drift calibration///////////////////////////////
  if(driftnum == 0) {
      values[driftnum] = angle_Gyro_z;
      driftnum = 1;
    }
    else if(driftnum >= 1){
      values[driftnum] = angle_Gyro_z;
      diffs[driftnum-1] = values[driftnum] - values[driftnum-1];
      if(driftnum == 50) {
        float sum = 0;
        float avg = 0;
        float avgcal = 0;
        driftnum = 0;
        for(int k = 0; k<49; k++){
          sum = sum + diffs[k];
        }
        avg = sum/49;
        avgcal = (diffs[0]+diffs[49])/2;
        if(((avgcal - avg)*(avgcal - avg))<=0.01){
          mySerial.println("stop moving");
          drifterror = avg;
          mySerial.println(drifterror);
        }
      }
      else driftnum++;
      delay(50);
    }


  //  _____ Read ADC _____
  if (count < arrsize) {
    ADC_Read_Value();

    sum1 += L_top;
    sum2 += R_top;
    sum3 += L_bottom;
    sum4 += R_bottom;

    count++;
  }
  if (count == arrsize) {
    L_top_offset = sum1 / arrsize;
    R_top_offset = sum2 / arrsize;
    L_bottom_offset = sum3 / arrsize;
    R_bottom_offset = sum4 / arrsize;
    offset_complete_flag = 1;
  }
  ADC_Read_Value();


  /*mySerial.print(L_top - L_top_offset);
    mySerial.print(" , ");
    mySerial.println(R_top - R_top_offset);
    //mySerial.print(",");
    mySerial.print(L_bottom - L_bottom_offset);
    mySerial.print(" , ");
    mySerial.println(R_bottom - R_bottom_offset);*/

  /*
    mySerial.print(avg_L_top - L_top_offset);
    mySerial.print(",");
    mySerial.print(avg_R_top - R_top_offset);
    mySerial.print(",");
    mySerial.print(avg_L_bottom - L_bottom_offset);
    mySerial.print(",");
    mySerial.println(avg_R_bottom - R_bottom_offset);*/

  if (offset_complete_flag) {
    vert_status = 0;
    horiz_status = 0;
    int16_t top_avg = ((L_top - L_top_offset) + (R_top - R_top_offset)) / 2;
    int16_t bottom_avg = ((L_bottom - L_bottom_offset) + (R_bottom - R_bottom_offset)) / 2;
    int16_t left_avg = ((L_top - L_top_offset) + (L_bottom - L_bottom_offset)) / 2;
    int16_t right_avg = ((R_top - R_top_offset) + (R_bottom - R_bottom_offset)) / 2;

    bool mov_vert_flag = (abs(top_avg - bottom_avg) > threshold) ? true : false;
    bool mov_horiz_flag = (abs(left_avg - right_avg) > threshold) ? true : false;

    if (mov_vert_flag) {
      if (top_avg > bottom_avg) vert_status = 1;
      else vert_status = -1;
    }
    if (mov_horiz_flag) {
      if (left_avg > right_avg) horiz_status = 1;
      else horiz_status = -1;
    }

    //mySerial.print(vert_status);
    //mySerial.print(" // ");
    //mySerial.println(horiz_status);
  }
  if (horiz_status == 1) {
    fin_z = fin_z - 1;
  }
  else if (horiz_status == -1) {
    fin_z = fin_z + 1;
  }
  else fin_z = fin_z;
  if (vert_status == 1) {
    fin_x = fin_x - 1;
  }
  else if (vert_status == -1) {
    fin_x = fin_x + 1;
  }
  else fin_x = fin_x;

//  mySerial.print(angle_z - fin_z);
//  mySerial.print(",");
//  mySerial.print(angle_x - fin_x);
//  mySerial.print(",");
//  mySerial.println(-angle_y);






  *TCA_LCMP0 = move_Servo(-angle_z + fin_z);
  *TCA_LCMP1 = move_Servo(angle_x + fin_x);
  *TCA_LCMP2 = move_Servo(-angle_y);

}
